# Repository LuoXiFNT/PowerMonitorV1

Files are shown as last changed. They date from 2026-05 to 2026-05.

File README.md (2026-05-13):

# PowerMonitorV1

* **PowerMonitorV1** 是一款基于 **STM32G030F6P6** 主控与 0.96 寸 I2C OLED 显示屏的便携式功率与电量监测计。

---

## 声明

* **开源协议**：本项目遵循 **GPL-3.0** 协议。
* **驱动来源**：本项目中的 0.96 寸 OLED 底层驱动库源自 **[江协科技 (Jiangxie Tech)](https://jiangxiekeji.com)**，将标准库的软件 I2C 重写成 HAL 库的非阻塞 I2C DMA 通信。
* **硬件工程**：本项目对应的 PCB 设计文件已发布至立创开源平台，硬件相应说明见连接 **[XT60功率与电量监测设备v1]( https://oshwhub.com/roboticlib/project_chgtzbxy)** 。

---

## 功能特性

* 使用 STM32G030F6P6 内部 12‑bit ADC 并过采样至 16‑bit，精确测量电压 (V) 与电流 (I)，实时计算功率 (P)。
* 根据系统运行时间自动累加总耗电量 (E / Wh)、总放电容量 (Q / mAh)。
* 支持 5 档屏幕刷新频率动态切换 (10ms ~ 200ms)。
* 内置交互状态机：画面冻结 (HOLD)、双视图切换、带二次确认的防误触数据清零。
* 包含电源指示灯与心跳灯，监测 MCU 是否在正常运行。
* 预留了一对 USART 接口，可以进一步开发与上位机的通信。

---

## 使用说明

设备配备四个独立按键 (`MENU`, `HOLD`, `CLR`, `UNIT`)，具体功能如下：

### 1. 视图切换 / 菜单 (MENU)
* **切换模式**：短按可在 **功率监测模式** (实时显示功率 P、电流 I、电压 V) 与 **电量统计模式** (累计显示能量 E、电量 Q、时间 T) 之间进行切换。
* **取消清零**：在弹出 `"Confirm CLEAR?"` 提示时，短按此键可取消操作并返回。

### 2. 画面冻结 (HOLD)
* **开启冻结**：短按可定格当前屏幕数据，停止刷新，便于记录瞬态数值。
* **取消冻结**：处于冻结状态时，**按下任意按键**即可立即解除锁定，恢复实时数据更新。

### 3. 安全清零 (CLR)
* **二次确认逻辑**：
    * **第一次短按**：进入待确认状态，屏幕提示 `"Confirm CLEAR?"`。
    * **第二次短按**：确认执行清零，后台所有累计数据 (能量 E、电量 Q、时间 T) 归零。
* *注：若需放弃清零，请在提示状态下按 `MENU` 键。*

### 4. 刷新率调节 (UNIT)
* **动态调整**：短按可循环调节 OLED 屏幕的渲染刷新周期。
* **档位循环**：`10ms` -> `25ms` -> `50ms` -> `100ms` -> `200ms` -> `10ms...`，依次循环。

---

## CUBEMX 配置说明

### I2C2 配置如图
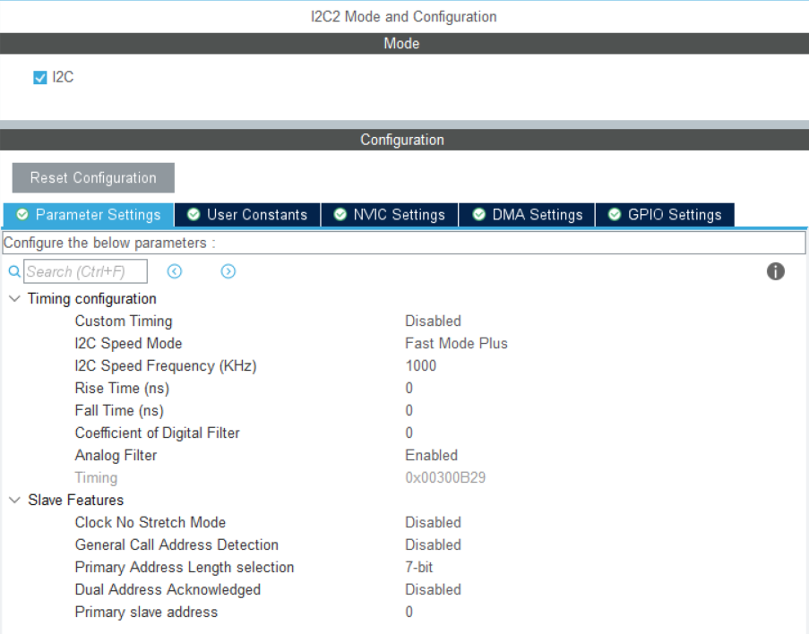
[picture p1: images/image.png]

### TIM3 配置如图
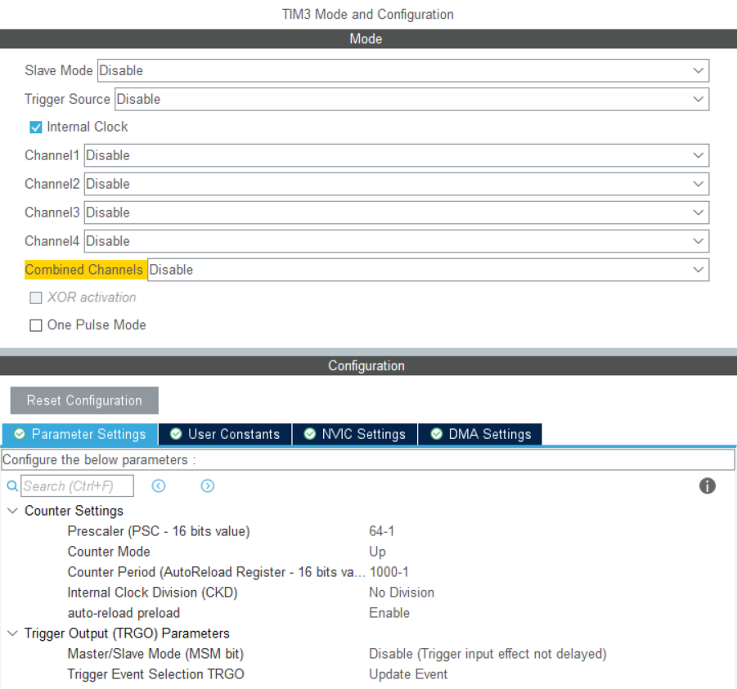
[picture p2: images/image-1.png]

### ADC1 配置如图
* 只需要开启 IN0 和 IN1 用来输入电流和电压的模拟采样信号。
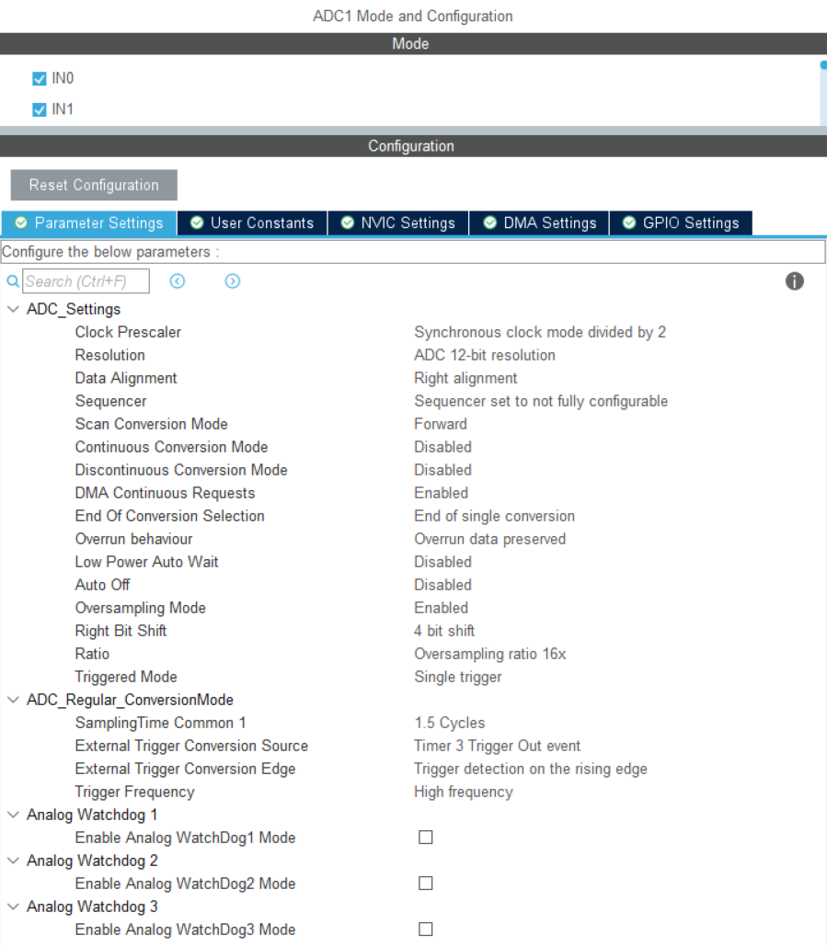
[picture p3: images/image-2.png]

### SYS 配置如图
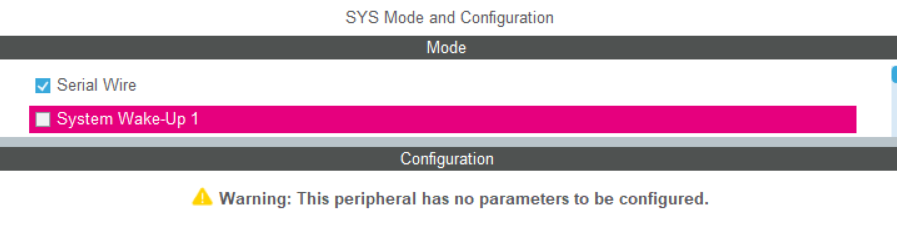
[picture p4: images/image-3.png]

### NVIC 配置如图
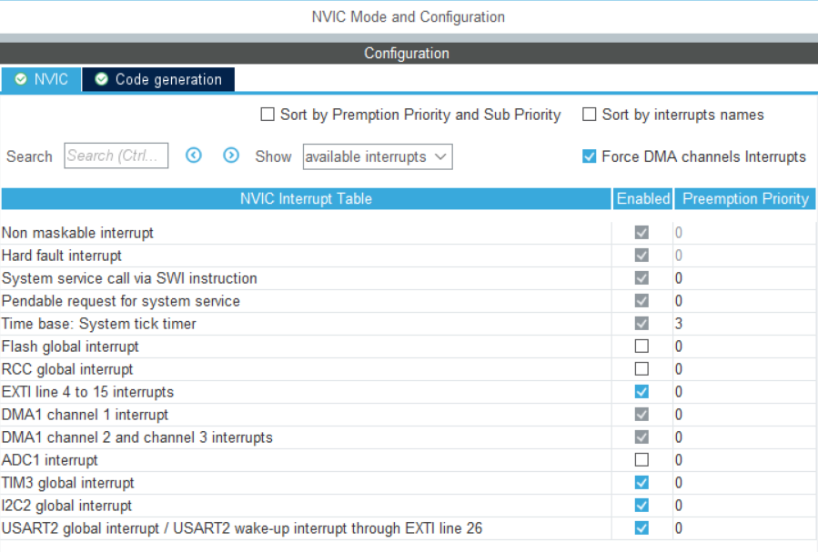
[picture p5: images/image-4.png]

### GPIO 以及 USER LABEL 设置如图
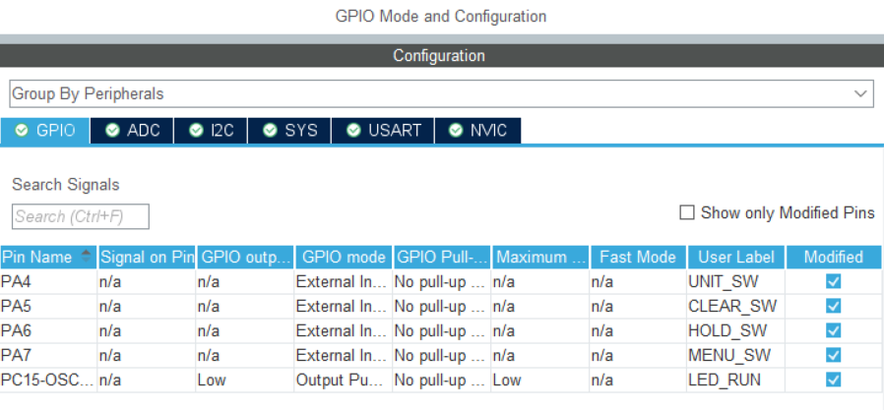
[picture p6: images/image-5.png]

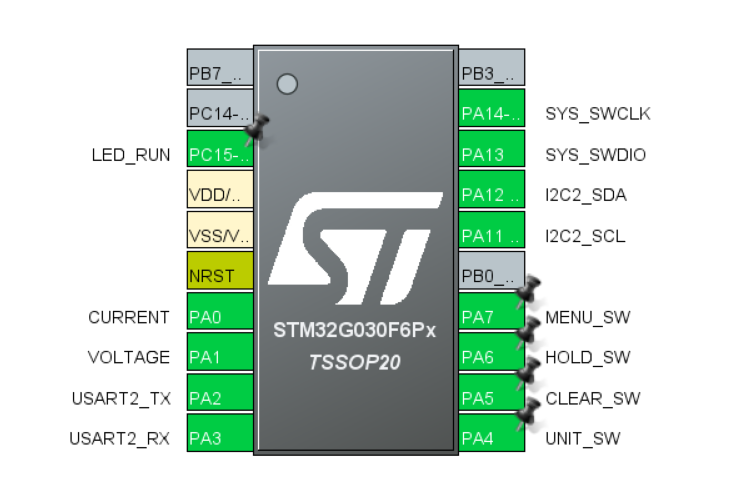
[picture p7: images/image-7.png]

### DMA 配置如图
* I2C2_RX 可以不启用 DMA 这里仅用于传输到 OLED 屏幕，不需要 RX 。
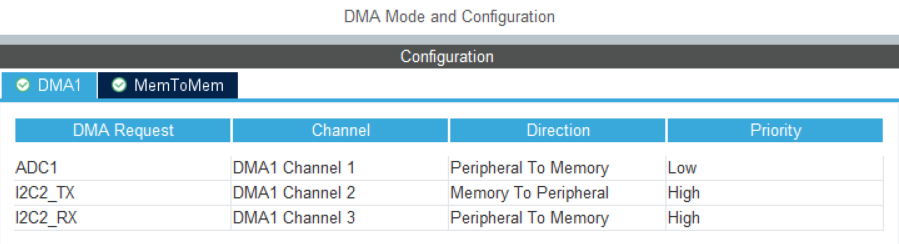
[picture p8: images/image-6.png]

### USART2 配置
* 这里只是启用了 USART2 ，如果需要相应功能可自行拓展。
### 时钟配置
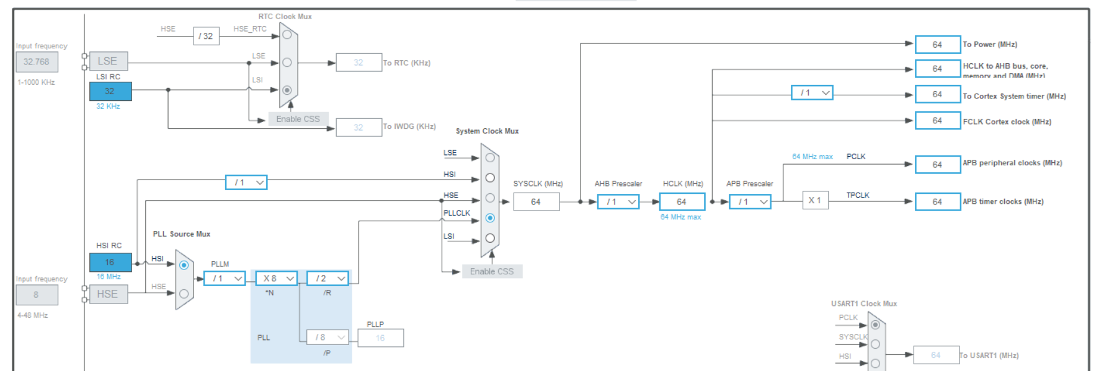
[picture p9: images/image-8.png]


## Keil 说明

### 必须用AC6编译器编译，编译必须选择-Oz image-size优化选项，否则会出现编译错误
* 移植工程的时候main函数内的ADC初始校准 **HAL_ADCEx_Calibration_Start(&hadc1);** **不能省略**，**否则**测量数据**严重失真**。

---
Copyright © 2026 LuoXiFNT

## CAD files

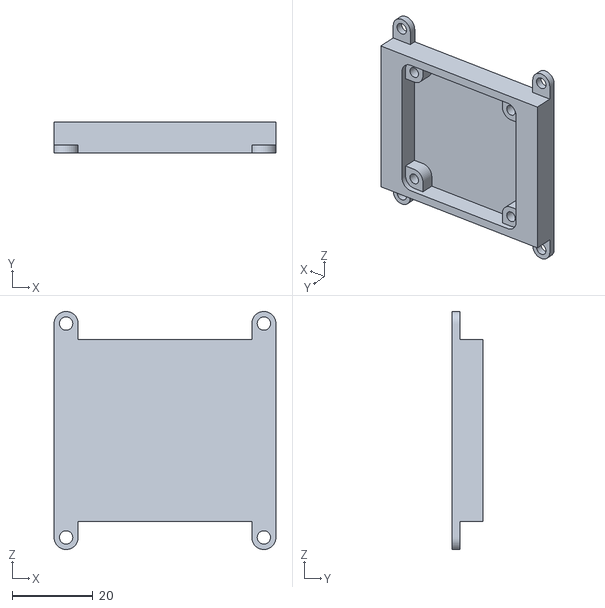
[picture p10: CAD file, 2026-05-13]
3Dmodels/外壳_下.STL
55.0 x 7.60 x 59.0

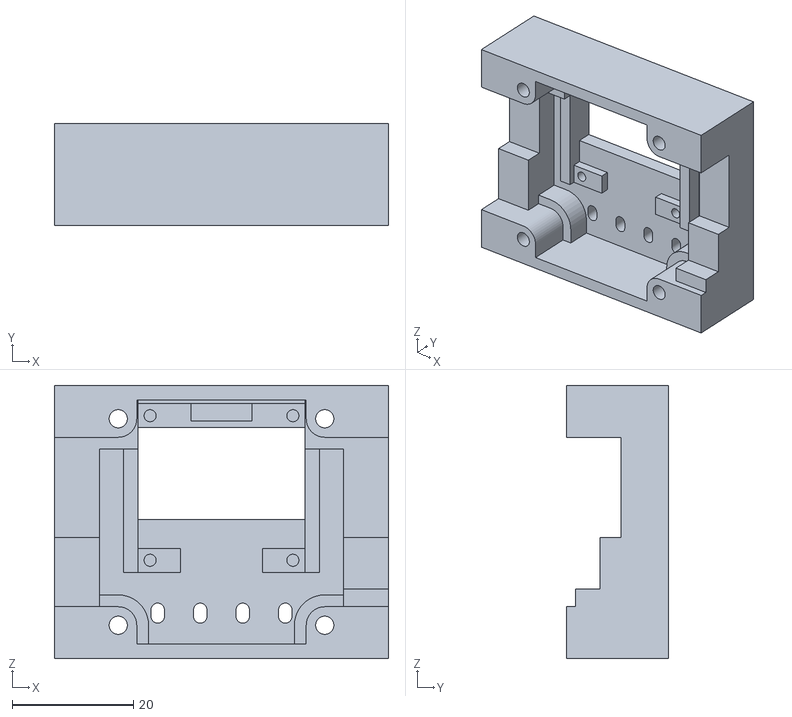
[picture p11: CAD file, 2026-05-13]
3Dmodels/外壳_上.STL
55.0 x 16.8 x 45.0

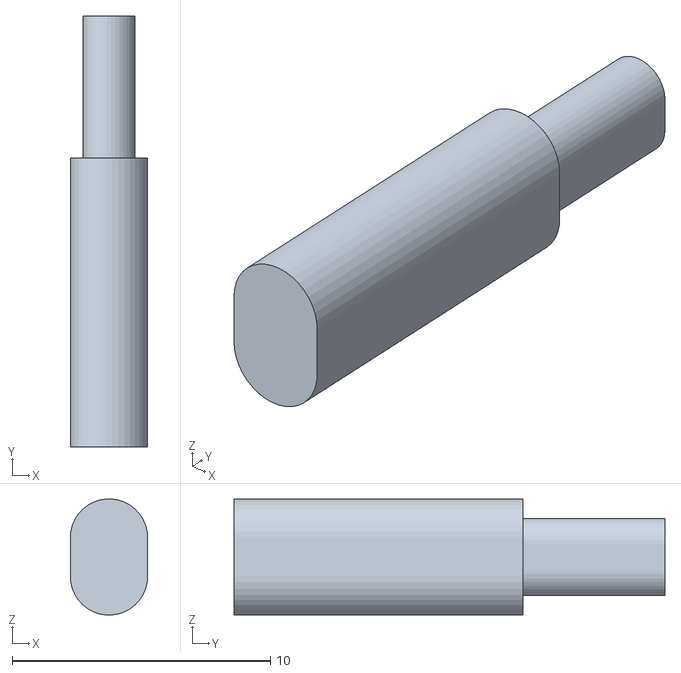
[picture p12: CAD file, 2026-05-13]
3Dmodels/按钮.STL
3.00 x 16.7 x 4.49

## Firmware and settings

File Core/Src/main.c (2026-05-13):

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
/* Includes ------------------------------------------------------------------*/
#include "main.h"
#include "adc.h"
#include "dma.h"
#include "i2c.h"
#include "tim.h"
#include "usart.h"
#include "gpio.h"

/* USER CODE BEGIN Includes */
#include "stdio.h"
#include "PowerMonitor.h"
#include "OLED.h"
/* USER CODE END Includes */


/* USER CODE BEGIN PV */
uint8_t usart_msg[30];
uint16_t adc_buff[2];
uint8_t display_flag = 0;
/* USER CODE END PV */

void SystemClock_Config(void);
/**
  * @brief  The application entry point.
  * @retval int
  */
int main(void)
{

  /* MCU Configuration--------------------------------------------------------*/

  /* Reset of all peripherals, Initializes the Flash interface and the Systick. */
  HAL_Init();

  /* Configure the system clock */
  SystemClock_Config();

  /* Initialize all configured peripherals */
  MX_GPIO_Init();
  MX_DMA_Init();
  MX_ADC1_Init();
  MX_I2C2_Init();
  MX_TIM3_Init();
  MX_USART2_UART_Init();
  /* USER CODE BEGIN 2 */
  OLED_Init();

  HAL_TIM_Base_Start_IT(&htim3);
  
  HAL_ADCEx_Calibration_Start(&hadc1); // ADC calibration (necessary)
  HAL_ADC_Start_DMA(&hadc1, (uint32_t *)adc_buff, 2);

  display_flag = 1; // trigger initial display update

  HAL_UART_Receive_IT(&huart2, usart_msg, 1); // WIP: USART command handling can be implemented in the future. For now, just echo back the received byte.

  /* USER CODE END 2 */

  /* Infinite loop */
  /* USER CODE BEGIN WHILE */
  while (1)
  {
    /* USER CODE END WHILE */

    /* USER CODE BEGIN 3 */

    if (display_flag && OLED_IsTxIdle()) // put display update in the main loop to avoid potential I2C transmission conflict with TIM interrupt
    {
      display_flag = 0;
      PM_Display_Update();
    }
  }
  /* USER CODE END 3 */
}

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
/* USER CODE BEGIN 4 */
void HAL_I2C_MasterTxCpltCallback(I2C_HandleTypeDef *hi2c)
{
  if (hi2c->Instance == I2C2)
  {
    OLED_I2C_OnTxCplt();
  }
}

void HAL_I2C_ErrorCallback(I2C_HandleTypeDef *hi2c)
{
  if (hi2c->Instance == I2C2)
  {
    OLED_I2C_OnError();
  }
}

void HAL_GPIO_EXTI_Falling_Callback(uint16_t GPIO_Pin)
{
  PM_Key_get(GPIO_Pin);
}

void HAL_UART_RxCpltCallback(UART_HandleTypeDef *huart)
{
  if (huart->Instance == USART2)
  {
    // WIP: USART command handling can be implemented here. For now, just echo back the received byte.

    HAL_UART_Transmit_IT(&huart2, usart_msg, 1);

    HAL_UART_Receive_IT(&huart2, usart_msg, 1);
  }
}

void HAL_TIM_PeriodElapsedCallback(TIM_HandleTypeDef *htim)
{
  if (htim->Instance == TIM3)
  {
    PM_LED_RUN(1000);

    PM_Key_Task();

    PM_ADC_Data_Update(adc_buff[0], adc_buff[1]); // transmit current adc_buff[0] and voltage adc_buff[1]
    
    if (PM_Display_Refresh())
    {
      display_flag = 1;
    }

  }
}

/* USER CODE END 4 */
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


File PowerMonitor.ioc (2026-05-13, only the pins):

Mcu.UserName=STM32G030F6Px
PA0.GPIO_Label=CURRENT
PA0.Signal=ADC1_IN0
PA1.GPIO_Label=VOLTAGE
PA1.Signal=ADC1_IN1
PA13.Signal=SYS_SWDIO
PA14-BOOT0.Signal=SYS_SWCLK
PA2.Signal=USART2_TX
PA3.Signal=USART2_RX
PA4.GPIO_Label=UNIT_SW
PA4.Signal=GPXTI4
PA5.GPIO_Label=CLEAR_SW
PA5.Signal=GPXTI5
PA6.GPIO_Label=HOLD_SW
PA6.Signal=GPXTI6
PA7.GPIO_Label=MENU_SW
PA7.Signal=GPXTI7

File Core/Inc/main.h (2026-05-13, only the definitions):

#define LED_RUN_Pin GPIO_PIN_15
#define LED_RUN_GPIO_Port GPIOC
#define CURRENT_Pin GPIO_PIN_0
#define CURRENT_GPIO_Port GPIOA
#define VOLTAGE_Pin GPIO_PIN_1
#define VOLTAGE_GPIO_Port GPIOA
#define UNIT_SW_Pin GPIO_PIN_4
#define UNIT_SW_GPIO_Port GPIOA
#define UNIT_SW_EXTI_IRQn EXTI4_15_IRQn
#define CLEAR_SW_Pin GPIO_PIN_5
#define CLEAR_SW_GPIO_Port GPIOA
#define CLEAR_SW_EXTI_IRQn EXTI4_15_IRQn
#define HOLD_SW_Pin GPIO_PIN_6
#define HOLD_SW_GPIO_Port GPIOA
#define HOLD_SW_EXTI_IRQn EXTI4_15_IRQn
#define MENU_SW_Pin GPIO_PIN_7
#define MENU_SW_GPIO_Port GPIOA
#define MENU_SW_EXTI_IRQn EXTI4_15_IRQn
#define I2C2_SCL_Pin GPIO_PIN_11
#define I2C2_SCL_GPIO_Port GPIOA
#define I2C2_SDA_Pin GPIO_PIN_12
#define I2C2_SDA_GPIO_Port GPIOA

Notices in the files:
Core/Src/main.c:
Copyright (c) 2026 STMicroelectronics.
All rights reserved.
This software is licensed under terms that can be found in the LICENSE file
